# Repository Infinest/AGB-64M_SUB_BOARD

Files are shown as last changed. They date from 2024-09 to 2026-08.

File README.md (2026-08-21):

# AGBSUBS1-01
This KiCAD PCB project aims to recreate the original AGBSUBS1-01 sub board meant for the original AGB 64M (E201843), 128M (E201850) and 256M (E201868) dev cartridges by Nintendo. Do note however, that it is not meant to be a 1:1 copy of the original PCB.

The board supports the following save types:
- 4kbit EEPROM
-  64kbit EEPROM
-  256kbit SRAM (via FRAM chip)
-  512kbit Flash
-  1Mbit Flash

## Ordering PCBs
A ready-to-manufacture set of Gerber files can found [here](https://github.com/Infinest/AGB-64M_SUB_BOARD/blob/master/Gerbers/AGB-64M_SUB_BOARD.zip).

### Important:
Make sure to order your PCBs with a thickness of 0.6mm or they may not fit into the cartridge.
For ease of soldering any fine-pitched components (like J1) ENIG as surface finish is recommended.

## BOM:

| Reference | Part Number | Description  |
| --- |:---:| -----:|
| R1, R2 | RC0201FR-0710KL (or equivalent) | 10K Ω resistor 0201 (0603 metric)|
| C1, C2, C3 | GRM033R60J104KE19D (or equivalent) | 0.1µF capacitor 0201 (0603 metric)|
| U1 | FM18W08-SG | 256kbit FRAM |
| U2 | MX29L010TC-15A1 or LE26FV10N1TS / SST39VF512 or SST39LF512 | 1Mbit Flash / 512kbit Flash  |
| U3 | 9854 / 9853 | 64kbit EEPROM / 4kbit EEPROM |
| J1 | AXK640347YG | Mezzanine connector |

### Note:
Per PCB only populate **ONE** of **U1**, **U2** or **U3**
- **R2** & **C2** should be added if U1 is being populated
- **R2** & **C3** should be added if U2 is being populated
- **R1** & **C1** should be added if U3 is being populated

## Examples
### 256kbit FRAM
256kbit FRAM

### 64kbit EEPROM
64kbit EEPROM

### 1Mbit Flash
1Mbit Flash

## Additional Images:




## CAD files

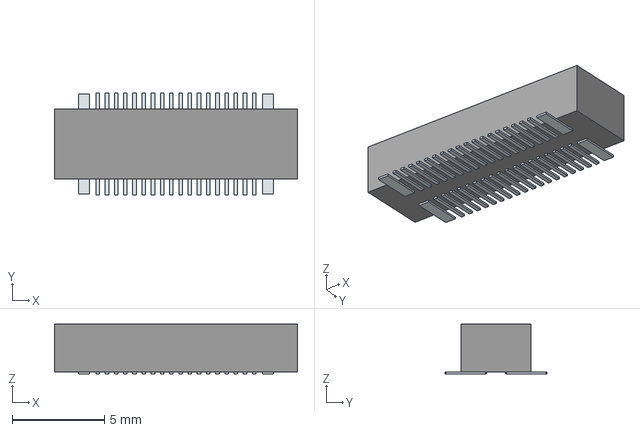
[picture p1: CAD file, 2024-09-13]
3dmodels/AXK640347YG.stp
13.2 x 5.55 x 2.70 mm
Pins

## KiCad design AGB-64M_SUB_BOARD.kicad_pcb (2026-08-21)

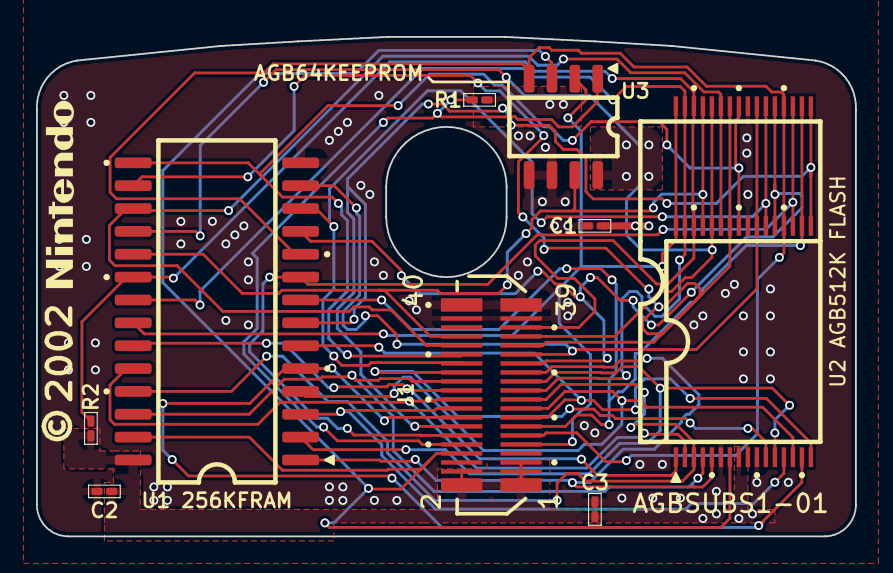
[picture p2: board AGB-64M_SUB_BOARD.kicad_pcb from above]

Board: 2 copper layers, 45.5 x 27.8 mm, 9 parts (0 on the bottom side), 30 nets.

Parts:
C1, C2, C3: 100nF; R_0201_0603Metric_Pad0.64x0.40mm_HandSolder
J1: AXK640347YG
R1, R2: 10K; R_0201_0603Metric_Pad0.64x0.40mm_HandSolder
U1 256KFRAM: FM18W08; SOIC-28W_7.5x17.9mm_P1.27mm
U2 AGB512K FLASH: U2; AGB-TSOP-I-32
U3: SSOP-8_3.9x5.05mm_P1.27mm

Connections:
/A0: J1.11 (A0), U1 256KFRAM.10 (A0), U2 AGB512K FLASH.20 (A0), U3.4 (A0)
/A1: J1.12 (A1), U1 256KFRAM.9 (A1), U2 AGB512K FLASH.19 (A1)
/A2: J1.13 (A2), U1 256KFRAM.8 (A2), U2 AGB512K FLASH.18 (A2)
/A3: J1.14 (A3), U1 256KFRAM.7 (A3), U2 AGB512K FLASH.17 (A3)
/A4: J1.15 (A4), U1 256KFRAM.6 (A4), U2 AGB512K FLASH.16 (A4)
/A5: J1.16 (A5), U1 256KFRAM.5 (A5), U2 AGB512K FLASH.15 (A5)
/A6: J1.17 (A6), U1 256KFRAM.4 (A6), U2 AGB512K FLASH.14 (A6)
/A7: J1.18 (A7), U1 256KFRAM.3 (A7), U2 AGB512K FLASH.13 (A7)
/A8: J1.19 (A8), U1 256KFRAM.25 (A8), U2 AGB512K FLASH.3 (A8)
/A9: J1.20 (A9), U1 256KFRAM.24 (A9), U2 AGB512K FLASH.2 (A9)
/A10: J1.21 (A10), U1 256KFRAM.21 (A10), U2 AGB512K FLASH.31 (A10)
/A11: J1.22 (A11), U1 256KFRAM.23 (A11), U2 AGB512K FLASH.1 (A11)
/A12: J1.23 (A12), U1 256KFRAM.2 (A12), U2 AGB512K FLASH.12 (A12)
/A13: J1.24 (A13), U1 256KFRAM.26 (A13), U2 AGB512K FLASH.4 (A13)
/A14: J1.25 (A14), U1 256KFRAM.1 (A14), U2 AGB512K FLASH.5 (A14)
/A15: J1.26 (A15), U2 AGB512K FLASH.11 (A15)
/D0: J1.27 (D0), U1 256KFRAM.11 (D0), U2 AGB512K FLASH.21 (D0)
/D1: J1.28 (D1), U1 256KFRAM.12 (D1), U2 AGB512K FLASH.22 (D1)
/D2: J1.29 (D2), U1 256KFRAM.13 (D2), U2 AGB512K FLASH.23 (D2)
/D3: J1.30 (D3), U1 256KFRAM.15 (D3), U2 AGB512K FLASH.25 (D3)
/D4: J1.31 (D4), U1 256KFRAM.16 (D4), U2 AGB512K FLASH.26 (D4)
/D5: J1.32 (D5), U1 256KFRAM.17 (D5), U2 AGB512K FLASH.27 (D5)
/D6: J1.33 (D6), U1 256KFRAM.18 (D6), U2 AGB512K FLASH.28 (D6)
/D7: J1.34 (D7), U1 256KFRAM.19 (D7), U2 AGB512K FLASH.29 (D7), U3.7 (D7)
GND: C1.2, C2.2, C3.2, J1.37 (GND), J1.38 (GND), J1.39 (GND), J1.40 (GND), U1 256KFRAM.14 (GND), U2 AGB512K FLASH.6 (GND), U2 AGB512K FLASH.10 (GND), U2 AGB512K FLASH.24 (GND), U3.5 (GND), U3.6 (GND)
unnamed: J1.35 (CS2), R2.2, U1 256KFRAM.20 (~CE), U2 AGB512K FLASH.30 (~CE)
unnamed: J1.10 (~CS), R1.2, U3.1 (~CS)
unnamed: J1.9 (~OE), U1 256KFRAM.22 (~OE), U2 AGB512K FLASH.32 (~OE), U3.2 (~OE)
unnamed: J1.8 (~WE), U1 256KFRAM.27 (~WE), U2 AGB512K FLASH.7 (~WE), U3.3 (~WE)
VCC: C1.1, C2.1, C3.1, J1.1 (VDD), J1.2 (VDD), J1.3 (VDD), J1.4 (VDD), J1.5 (VDD), R1.1, R2.1, U1 256KFRAM.28 (VCC), U2 AGB512K FLASH.8 (VCC), U3.8 (VCC)
